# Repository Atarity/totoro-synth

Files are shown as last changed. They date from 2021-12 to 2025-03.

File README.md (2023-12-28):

# Totoro synth
Totoro is a portable, analog synth made on top of MCP6004 opamp. It features 2 VCOs (one could act as LFO) and simple VCF. Here it is [a short video demo](https://www.youtube.com/watch?v=yHeWAp9w_LM).

This open-source project based on [original design](https://syntherjack.net/totoro-1-ic-simple-synth/) of SyntherJack's Totoro and published with his permission.

In v1.0.1:
- Some of the components were rearranged
- Batteries moved on top side of PCB so overall assembly is almost 2 times thinner now
- Minor layout issues were fixed.

### Useful links
- [Bill of Materials v1.0.1](https://docs.google.com/spreadsheets/d/1fobkR_ruTiGQf1n50Jt4_U9o5RTrw8VCa_eaik46wdc/edit?usp=sharing)
- [Assembly details (RU)](https://snnkv.com/projects/totoro-slim/)
- [My list of open-source, standalone synths](https://diy-synths.snnkv.com/)

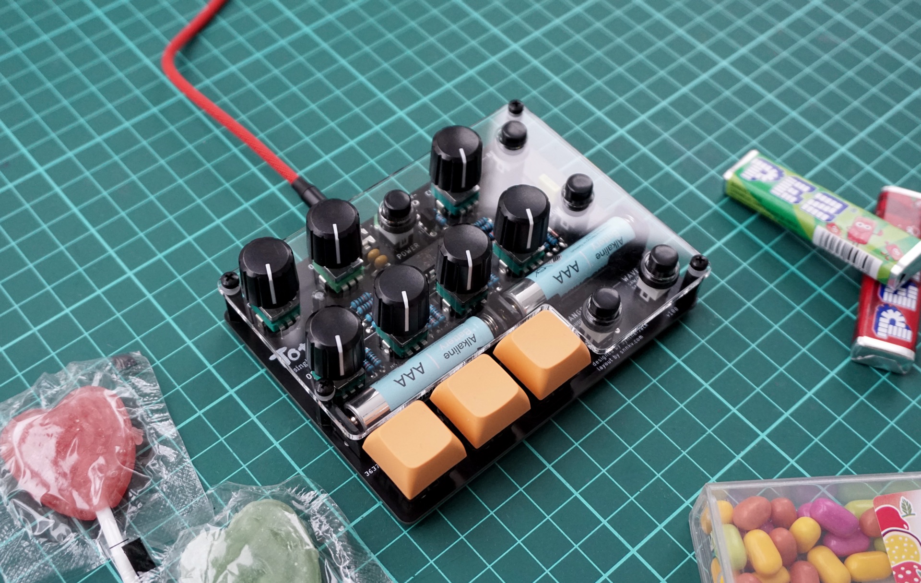
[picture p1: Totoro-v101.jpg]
Totoro


Enjoy the drone (under [CC-BY-NC-SA](https://creativecommons.org/licenses/by-nc-sa/4.0/deed.en))!

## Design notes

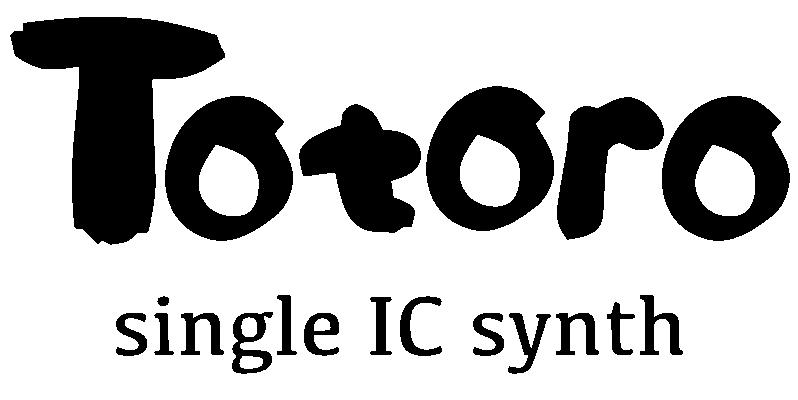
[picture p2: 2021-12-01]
PCB art/single-1bit.bmp

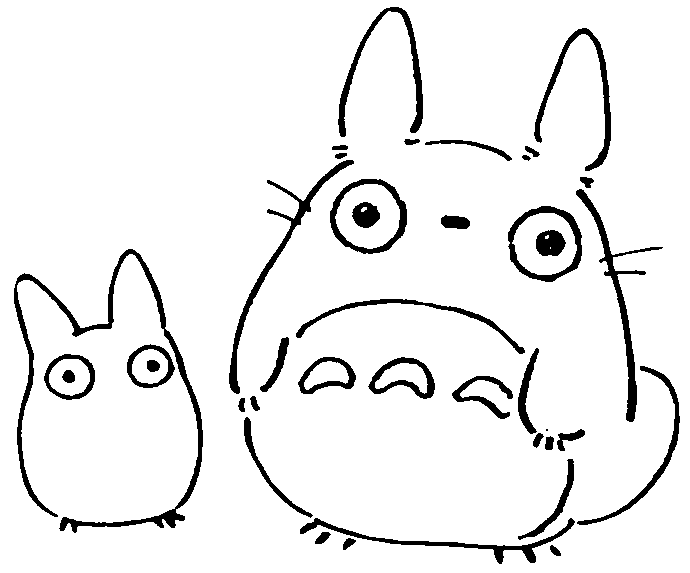
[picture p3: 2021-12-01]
PCB art/tot3-1bit.bmp

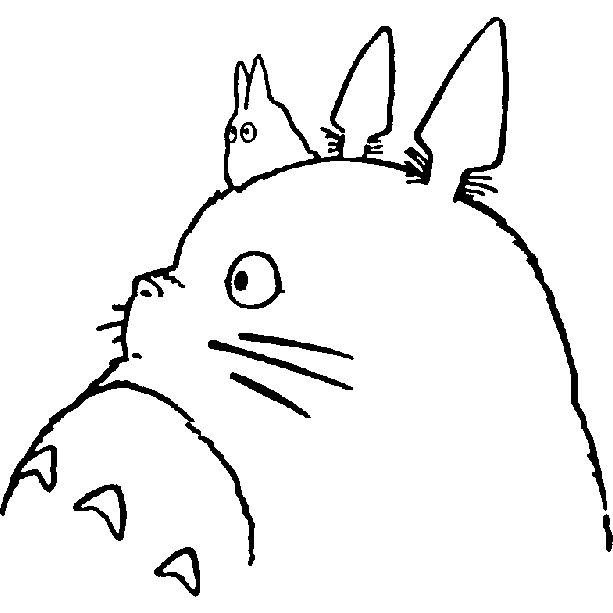
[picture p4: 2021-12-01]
PCB art/ghibli-1bit.bmp

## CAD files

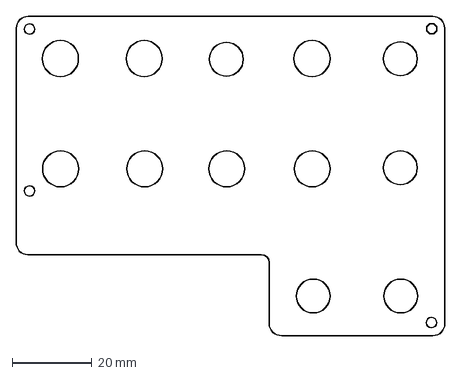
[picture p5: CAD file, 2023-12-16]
Cover/Totoro-top-v101.dxf
107.6 x 80.2 mm

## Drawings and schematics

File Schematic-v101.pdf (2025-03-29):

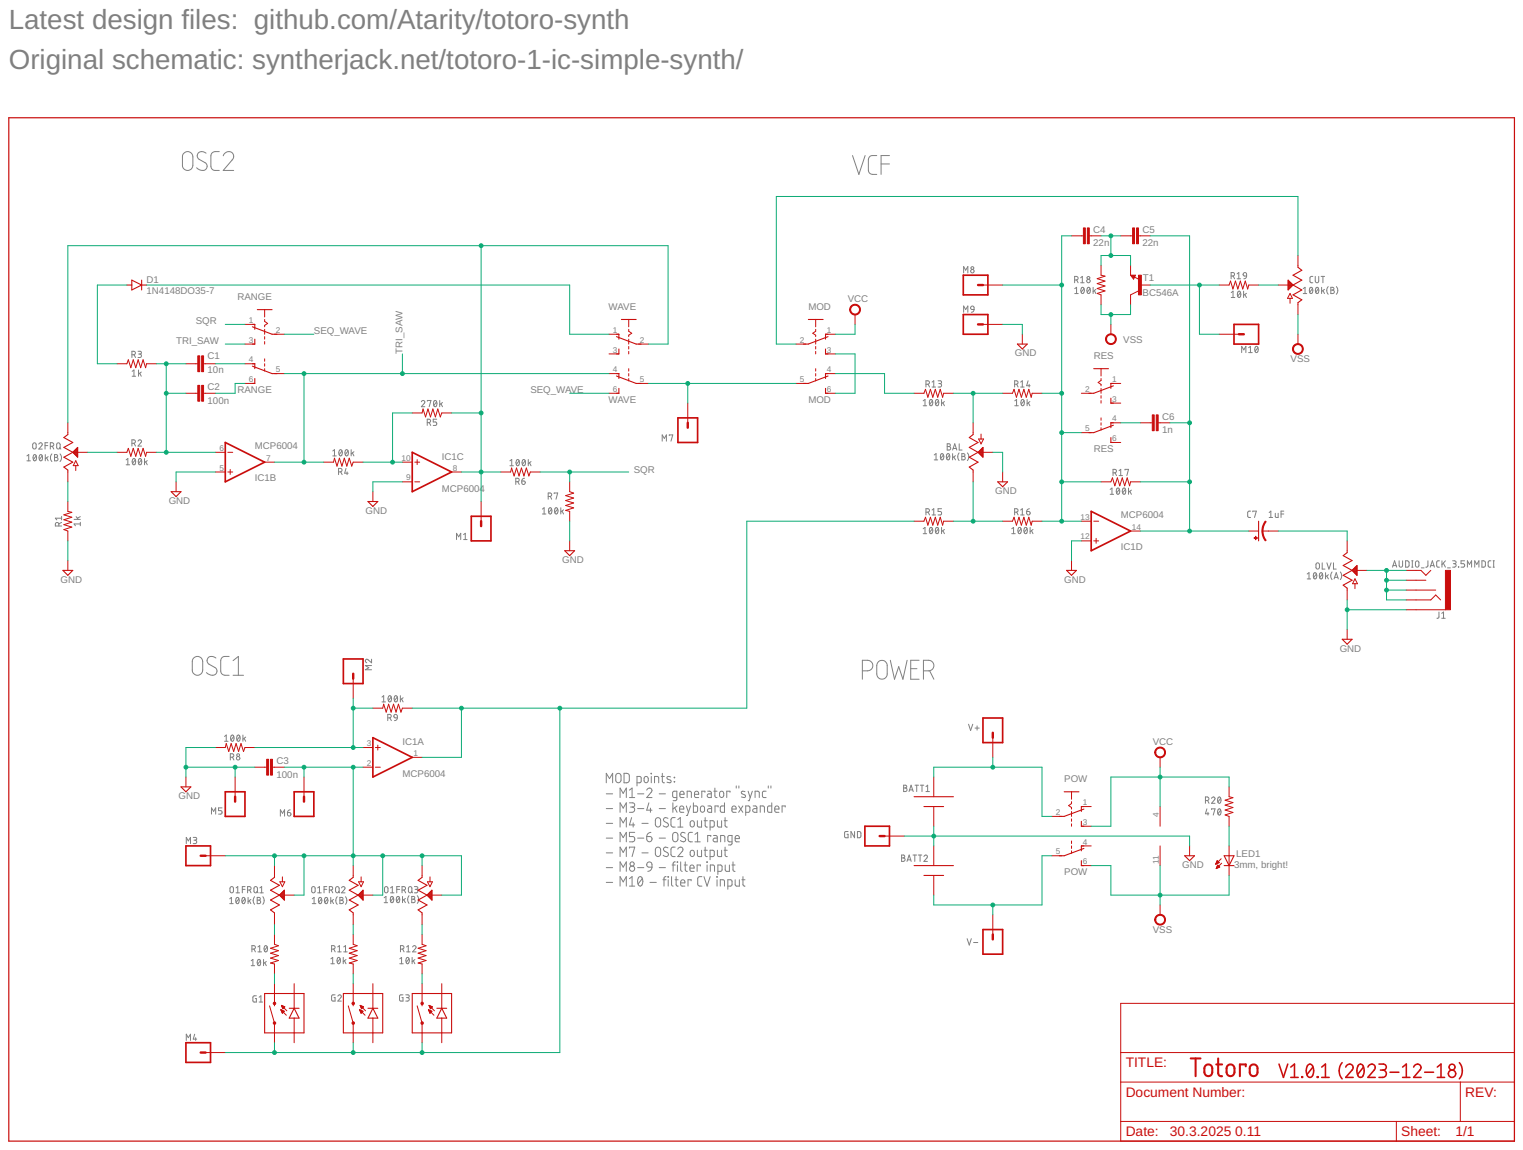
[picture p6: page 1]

Latest design files: github.com/Atarity/totoro-synth
Original schematic: syntherjack.net/totoro-1-ic-simple-synth/

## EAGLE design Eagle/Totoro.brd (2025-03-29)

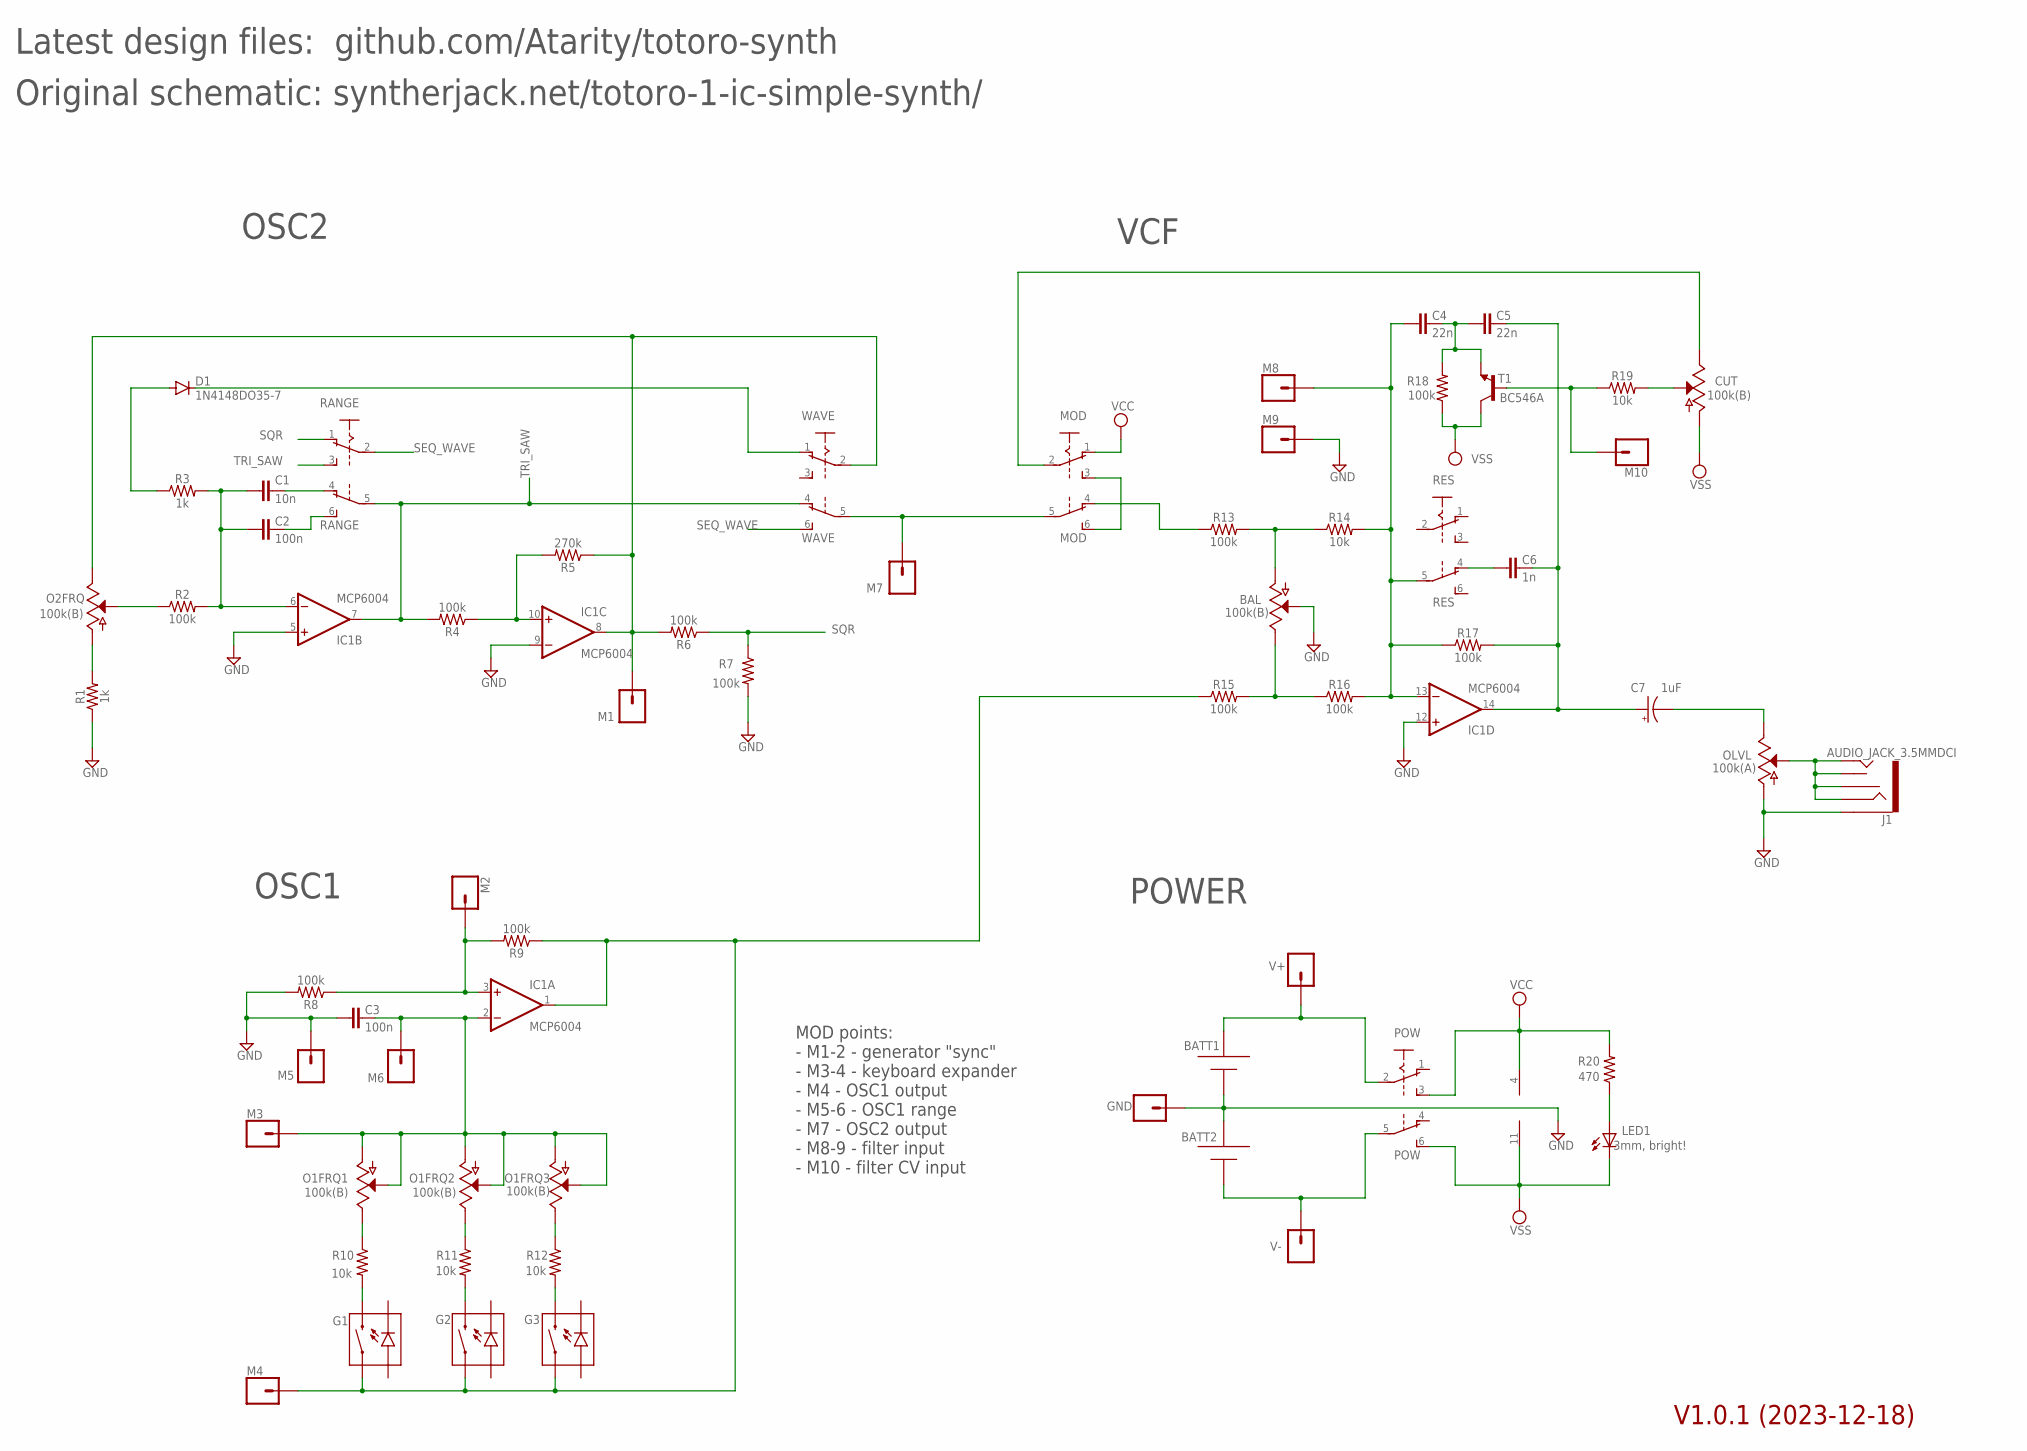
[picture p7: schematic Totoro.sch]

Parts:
BAL: 100k(B); POT-PTH-ALPS-KIT
BATT1, BATT2: ATARITY-AAAKLS5-817D; KLS5-817-D
C1: 10n; C050-024X044
C2, C3: 100n; C050-024X044
C4, C5: 22n; C050-024X044
C6: 1n; C050-024X044
C7: 1uF; CPOL-RADIAL-2.5MM-5MM
CUT: 100k(B); POT-PTH-ALPS-KIT
D1: 1N4148DO35-7; DO35-7
G1, G2, G3: MECHANICAL-KEYBOARD1U; CHERRY-MX-LED-1U
GND: CONN_01; 1X01
IC1: MCP6004; DIL14
J1: AUDIO_JACK_3.5MMDCI; DCI-ST-033
LED1: 3mm, bright!; LED3MM
M1, M2, M3, M4, M5, M6, M7, M8, M9, M10: CONN_01; 1X01
MOD: PB22E07
O1FRQ1, O1FRQ2, O1FRQ3, O2FRQ: 100k(B); POT-PTH-ALPS-KIT
OLVL: 100k(A); POT-PTH-ALPS-KIT
POW: PB22E07
R1, R3: 1k; AXIAL-0.3
R2, R4, R6, R7, R8, R9, R13, R15, R16, R17, R18: 100k; AXIAL-0.3
R5: 270k; AXIAL-0.3
R10, R11, R12, R14, R19: 10k; AXIAL-0.3
R20: 470; AXIAL-0.3
RANGE: PB22E07
RES: PB22E07
T1: BC546A; TO92-EBC
V+: CONN_01; 1X01
V-: CONN_01; 1X01
WAVE: PB22E07

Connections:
GND: BAL.P$2 (S), BATT1.+, BATT2.-, C3.2, GND.1, IC1.5 (+IN), IC1.9 (-IN), IC1.12 (+IN), J1.P2 (SLEEVE), J1.P3 (SLEEVE), M5.1, M9.1, OLVL.P$1 (A), R1.P$1 (1), R7.P$2 (2), R8.P$2 (2)
unnamed: C1.2, C2.2, IC1.6 (-IN), R2.P$2 (2), R3.P$2 (2)
unnamed: O2FRQ.P$2 (S), R2.P$1 (1)
unnamed: O2FRQ.P$1 (A), R1.P$2 (2)
unnamed: C1.1, RANGE.4 (O)
unnamed: C2.1, RANGE.6 (S)
unnamed: M7.1, MOD.5, WAVE.5
unnamed: IC1.10 (+IN), R4.P$1 (1), R5.P$2 (2)
unnamed: IC1.8 (OUT), M1.1, O2FRQ.P$3 (E), R5.P$1 (1), R6.P$2 (2), WAVE.2
unnamed: D1.A, R3.P$1 (1)
unnamed: D1.C, WAVE.1 (O)
unnamed: MOD.3 (S), MOD.6 (S)
unnamed: MOD.4 (O), R13.P$1 (1)
unnamed: BAL.P$3 (E), R15.P$2 (2), R16.P$1 (1)
unnamed: BAL.P$1 (A), R13.P$2 (2), R14.P$1 (1)
unnamed: C4.2, IC1.13 (-IN), M8.1, R14.P$2 (2), R16.P$2 (2), R17.P$1 (1), RES.5
unnamed: C6.2, RES.4 (O)
unnamed: C5.1, C6.1, C7.1 (+), IC1.14 (OUT), R17.P$2 (2)
unnamed: M10.1, R19.P$1 (1), T1.B
unnamed: C4.1, C5.2, R18.P$2 (2), T1.E
unnamed: CUT.P$2 (S), R19.P$2 (2)
unnamed: CUT.P$3 (E), MOD.2
unnamed: C7.2 (-), OLVL.P$3 (E)
unnamed: J1.P0 (TIP), J1.P1 (RING), J1.P4 (RSH), J1.P5 (TSH), OLVL.P$2 (S)
unnamed: O1FRQ3.P$3 (E), R12.P$1 (1)
unnamed: G1.S2 (2), R10.P$2 (2)
unnamed: O1FRQ2.P$3 (E), R11.P$1 (1)
unnamed: G2.S2 (2), R11.P$2 (2)
unnamed: O1FRQ1.P$3 (E), R10.P$1 (1)
unnamed: G3.S2 (2), R12.P$2 (2)
unnamed: C3.1, IC1.2 (-IN), M3.1, M6.1, O1FRQ1.P$1 (A), O1FRQ1.P$2 (S), O1FRQ2.P$1 (A), O1FRQ2.P$2 (S), O1FRQ3.P$1 (A), O1FRQ3.P$2 (S)
unnamed: IC1.3 (+IN), M2.1, R8.P$1 (1), R9.P$2 (2)
unnamed: G1.S1 (1), G2.S1 (1), G3.S1 (1), IC1.1 (OUT), M4.1, R9.P$1 (1), R15.P$1 (1)
unnamed: LED1.A, R20.P$1 (1)
unnamed: BATT1.-, POW.2, V+.1
unnamed: BATT2.+, POW.5, V-.1
SEQ_WAVE: RANGE.2, WAVE.6 (S)
SQR: R6.P$1 (1), R7.P$1 (1), RANGE.1 (O)
TRI_SAW: IC1.7 (OUT), R4.P$2 (2), RANGE.3 (S), RANGE.5, WAVE.4 (O)
VCC: IC1.4 (V+), MOD.1 (O), POW.3 (S), R20.P$2 (2)
VSS: CUT.P$1 (A), IC1.11 (V-), LED1.K (C), POW.6 (S), R18.P$1 (1), T1.C

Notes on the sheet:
Original schematic: syntherjack.net/totoro-1-ic-simple-synth/
OSC2
VCF
OSC1
POWER
Latest design files: github.com/Atarity/totoro-synth
V1.0.1 (2023-12-18)
MOD points: - M1-2 - generator "sync" - M3-4 - keyboard expander - M4 - OSC1 output - M5-6 - OSC1 range - M7 - OSC2 output - M8-9 - filter input - M10 - filter CV input

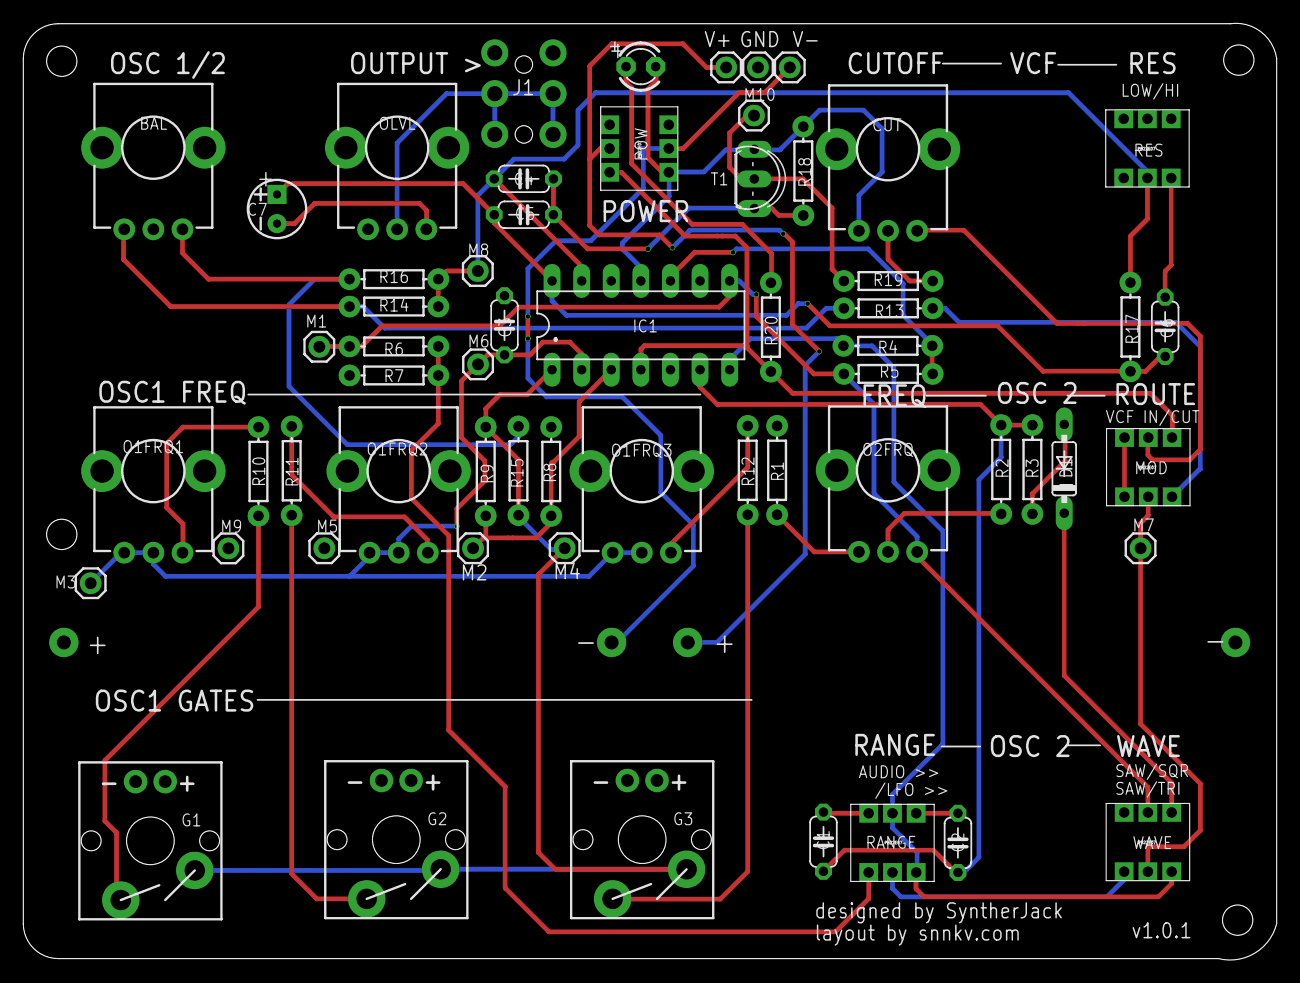
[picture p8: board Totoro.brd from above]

Board: 2 copper layers, 107.5 x 80.4 mm, 62 parts (0 on the bottom side), 41 nets.

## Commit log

2022-05-06 pic, outdated gerbers
2023-08-08 v100 added with minor fixes and ontop batteries
    [BOM-Totoro-v100.csv, BOM-Totoro.xlsx, Totoro-all.dxf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]
2023-12-16 version 101
    [BOM-Totoro-v100.csv, Totoro-top-v101.dxf, Totoro.brd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]
2023-12-18 100k pot fix
    [Totoro.brd, Totoro.sch]
2025-03-29 Transistor symbol fix
    [Totoro.brd, Totoro.sch]

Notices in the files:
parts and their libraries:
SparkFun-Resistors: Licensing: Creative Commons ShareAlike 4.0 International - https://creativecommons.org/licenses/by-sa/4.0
